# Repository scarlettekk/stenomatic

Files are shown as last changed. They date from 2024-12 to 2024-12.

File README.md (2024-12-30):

Stenomatic is an open source stenotype keyboard designed for an elegant yet inexpensive typing experience. This repository hosts all the files and information needed to produce one, which anyone can do for their own use. You may use your Stenomatic for any purpose you like, but you may not produce Stenomatics for the express purpose of selling them.

*Note: Photos of the keyboard in this document are of v2.0, when the Left S and * keys were rotated incorrectly, hence they only had 1u keycaps. This is fixed in the current version and 2u keycaps can be used.*

Stenomatic uses [Kailh Choc Pink switches](https://www.kailhswitch.com/mechanical-keyboard-switches/choc-pro-pink-keyboard-switch.html) for the most similar experience to a professional stenotype machine.

[Stenomatic](https://github.com/scarlettekk/stenomatic) © 2024 by [Cora Shuryn](https://github.com/scarlettekk/) is licensed under [CC BY-NC-SA 4.0](https://creativecommons.org/licenses/by-nc-sa/4.0/?ref=chooser-v1)

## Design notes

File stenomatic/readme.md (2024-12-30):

# stenomatic

stenomatic

*A short description of the keyboard/project*

* Keyboard Maintainer: [Cora Shuryn](https://github.com/scarlettekk)
* Hardware Supported: *Seeed Studio XIAO RP2040*

Make example for this keyboard (after setting up your build environment):

    qmk compile -kb stenomatic -km default

Flashing example for this keyboard:

    qmk flash -kb stenomatic -km default

See the [build environment setup](https://docs.qmk.fm/#/getting_started_build_tools) and the [make instructions](https://docs.qmk.fm/#/getting_started_make_guide) for more information. Brand new to QMK? Start with our [Complete Newbs Guide](https://docs.qmk.fm/#/newbs).

## Bootloader

Enter the bootloader in 2 ways:

* **Bootmagic reset**: Hold down the key at (0,0) in the matrix (Left S) and plug in the keyboard
* **Physical reset button**: Plug in keyboard while bootloader button on XIAO is pressed

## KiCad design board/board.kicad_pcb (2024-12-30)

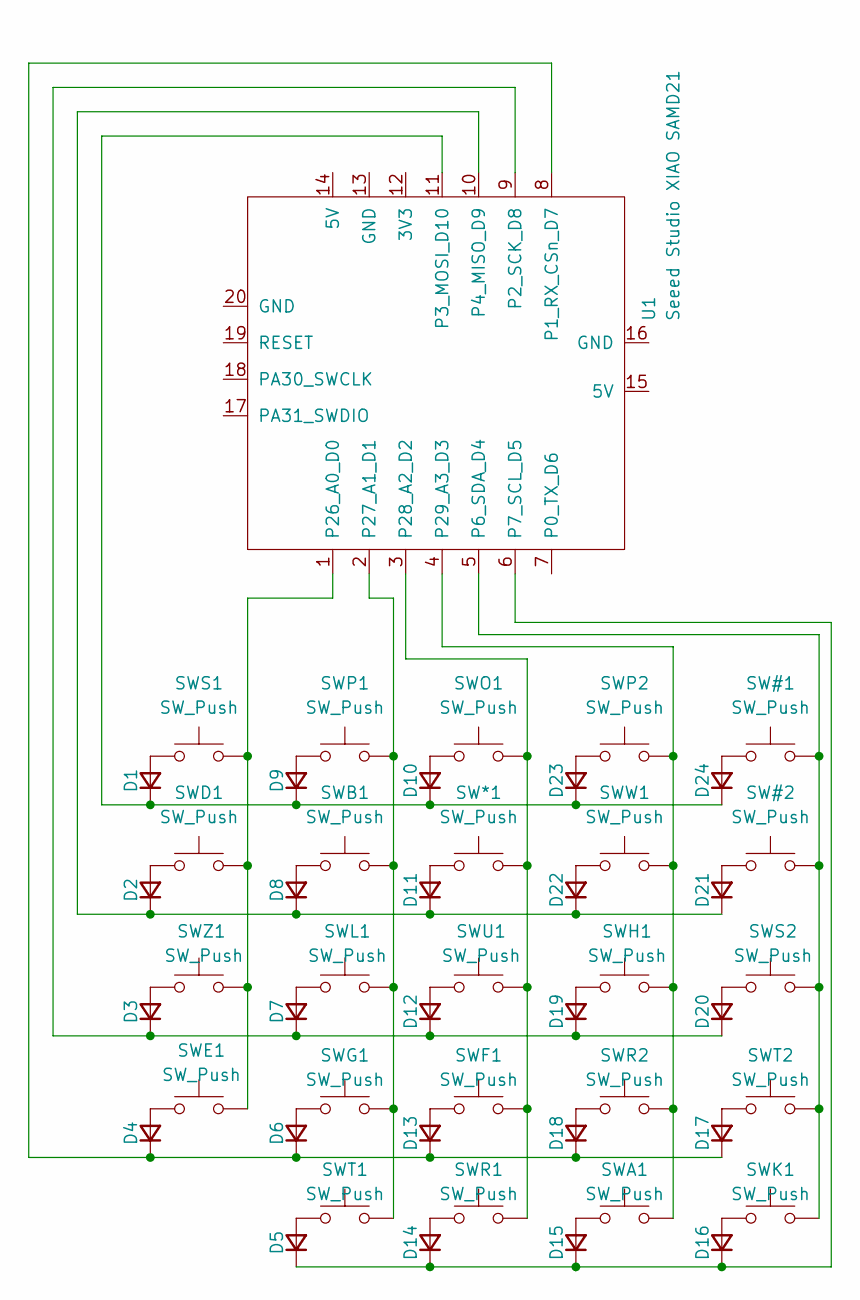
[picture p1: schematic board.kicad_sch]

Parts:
D1, D2, D3, D4, D5, D6, D7, D8, D9, D10, D11, D12, D13, D14, D15, D16, D17, D18, D19, D20, D21, D22, D23, D24: D_Small; D_DO-41_SOD81_P7.62mm_Horizontal
SW#1, SW#2: SW_Push; SW_Matias_1.00u
SW*1: SW_Push; SW_Matias_1.00u
SWA1: SW_Push; SW_Matias_1.00u
SWB1: SW_Push; SW_Matias_1.00u
SWD1: SW_Push; SW_Matias_1.00u
SWE1: SW_Push; SW_Matias_1.00u
SWF1: SW_Push; SW_Matias_1.00u
SWG1: SW_Push; SW_Matias_1.00u
SWH1: SW_Push; SW_Matias_1.00u
SWK1: SW_Push; SW_Matias_1.00u
SWL1: SW_Push; SW_Matias_1.00u
SWO1: SW_Push; SW_Matias_1.00u
SWP1, SWP2: SW_Push; SW_Matias_1.00u
SWR1, SWR2: SW_Push; SW_Matias_1.00u
SWS1, SWS2: SW_Push; SW_Matias_1.00u
SWT1, SWT2: SW_Push; SW_Matias_1.00u
SWU1: SW_Push; SW_Matias_1.00u
SWW1: SW_Push; SW_Matias_1.00u
SWZ1: SW_Push; SW_Matias_1.00u
U1: Seeed Studio XIAO SAMD21; XIAO-SAMD21-RP2040-14P-2.54-21X17.8MM (Seeeduino XIAO)

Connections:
unnamed: D1.2 (A), SWS1.1
unnamed: D1.1 (K), D9.1 (K), D10.1 (K), D23.1 (K), D24.1 (K), U1.11 (P3_MOSI_D10)
unnamed: D2.2 (A), SWD1.1
unnamed: D3.2 (A), SWZ1.1
unnamed: D4.2 (A), SWE1.1
unnamed: D5.2 (A), SWT1.1
unnamed: D6.2 (A), SWG1.1
unnamed: D7.2 (A), SWL1.1
unnamed: D8.2 (A), SWB1.1
unnamed: D9.2 (A), SWP1.1
unnamed: D10.2 (A), SWO1.1
unnamed: D11.2 (A), SW*1.1
unnamed: D2.1 (K), D8.1 (K), D11.1 (K), D21.1 (K), D22.1 (K), U1.10 (P4_MISO_D9)
unnamed: D12.2 (A), SWU1.1
unnamed: D3.1 (K), D7.1 (K), D12.1 (K), D19.1 (K), D20.1 (K), U1.9 (P2_SCK_D8)
unnamed: D13.2 (A), SWF1.1
unnamed: D4.1 (K), D6.1 (K), D13.1 (K), D17.1 (K), D18.1 (K), U1.8 (P1_RX_CSn_D7)
unnamed: D14.2 (A), SWR1.1
unnamed: D5.1 (K), D14.1 (K), D15.1 (K), D16.1 (K), U1.6 (P7_SCL_D5)
unnamed: D15.2 (A), SWA1.2
unnamed: D16.2 (A), SWK1.1
unnamed: D17.2 (A), SWT2.1
unnamed: D18.2 (A), SWR2.2
unnamed: D19.2 (A), SWH1.2
unnamed: D20.2 (A), SWS2.1
unnamed: D21.2 (A), SW#2.1
unnamed: D22.2 (A), SWW1.2
unnamed: D23.2 (A), SWP2.2
unnamed: D24.2 (A), SW#1.1
unnamed: SW#1.2, SW#2.2, SWK1.2, SWS2.2, SWT2.2, U1.5 (P6_SDA_D4)
unnamed: SWD1.2, SWE1.2, SWS1.2, SWZ1.2, U1.1 (P26_A0_D0)
unnamed: SWB1.2, SWG1.2, SWL1.2, SWP1.2, SWT1.2, U1.2 (P27_A1_D1)
unnamed: SW*1.2, SWF1.2, SWO1.2, SWR1.2, SWU1.2, U1.3 (P28_A2_D2)
unnamed: SWA1.1, SWH1.1, SWP2.1, SWR2.1, SWW1.1, U1.4 (P29_A3_D3)

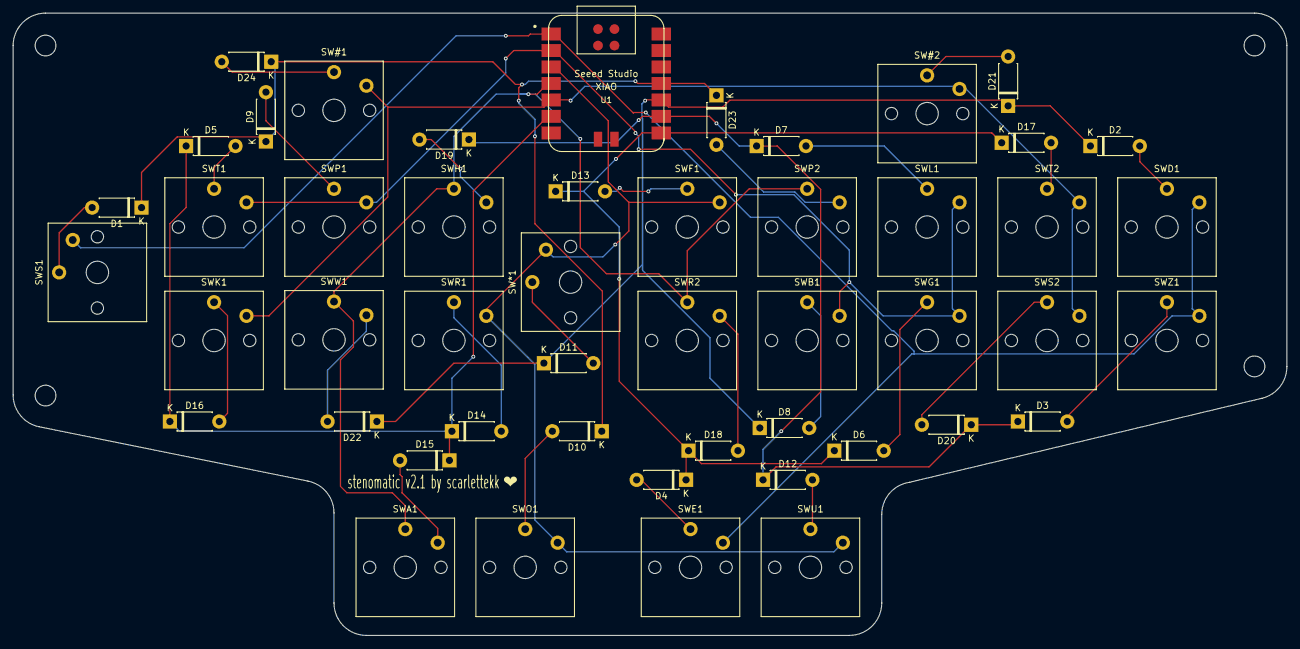
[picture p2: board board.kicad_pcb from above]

Board: 2 copper layers, 196.5 x 96.0 mm, 49 parts (0 on the bottom side), 34 nets.

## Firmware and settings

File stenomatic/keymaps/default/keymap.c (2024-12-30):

#include QMK_KEYBOARD_H
#include "print.h"

const uint16_t PROGMEM keymaps[][MATRIX_ROWS][MATRIX_COLS] = {
    [0] = LAYOUT(
        STN_SL, STN_PL, STN_O, 	  STN_PR, STN_NUM, // Row 1
        STN_DR, STN_BR, STN_STR,  STN_WL, STN_NUM, // Row 2
        STN_ZR, STN_LR, STN_U,    STN_HL, STN_SR,   // Row 3
        STN_E, 	STN_GR, STN_FR,   STN_RR, STN_TR,  // Row 4
        STN_TL, STN_RL, STN_A,    STN_KL           // Row 5
    )
};

void keyboard_pre_init_user(void) {
    gpio_set_pin_output(GP16);
    gpio_set_pin_output(GP17);
    gpio_set_pin_output(GP25);

}

void keyboard_post_init_user(void) {
    gpio_write_pin_high(GP16);
    gpio_write_pin_high(GP17);
    gpio_write_pin_high(GP25);

}

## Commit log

2024-10-09 switch to THT diodes for ease of installation
    [board-CuBottom.gbr, board-CuTop.gbr, board-EdgeCuts.gbr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]
2024-10-09 update jlcpcb schematics
    [board-CuBottom.gbr, board-CuTop.gbr, board-EdgeCuts.gbr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]
2024-10-09 missing trace
    [board-CuBottom.gbr, board-CuTop.gbr, board-EdgeCuts.gbr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]
2024-10-09 remove spurious silkscreen
    [board-CuBottom.gbr, board-CuTop.gbr, board-EdgeCuts.gbr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]
2024-10-09 mounting holes
    [board.kicad_pcb]
2024-10-13 add firmware, switch to choc keys, rewire (v2)
    [board.kicad_pcb, board.kicad_sch]
2024-10-13 add 3d models
    [board.kicad_pcb]
2024-10-13 update jlcpcb files
    [board-CuBottom.gbr, board-CuTop.gbr, board-EdgeCuts.gbr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]
2024-10-13 add another mounting hole
    [board-CuBottom.gbr, board-CuTop.gbr, board-EdgeCuts.gbr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]
